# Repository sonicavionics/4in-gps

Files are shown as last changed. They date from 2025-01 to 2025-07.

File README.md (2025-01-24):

# GPS Module Repository

Use Export KiCad Images Workflow

---

<div align="center">
  <div>
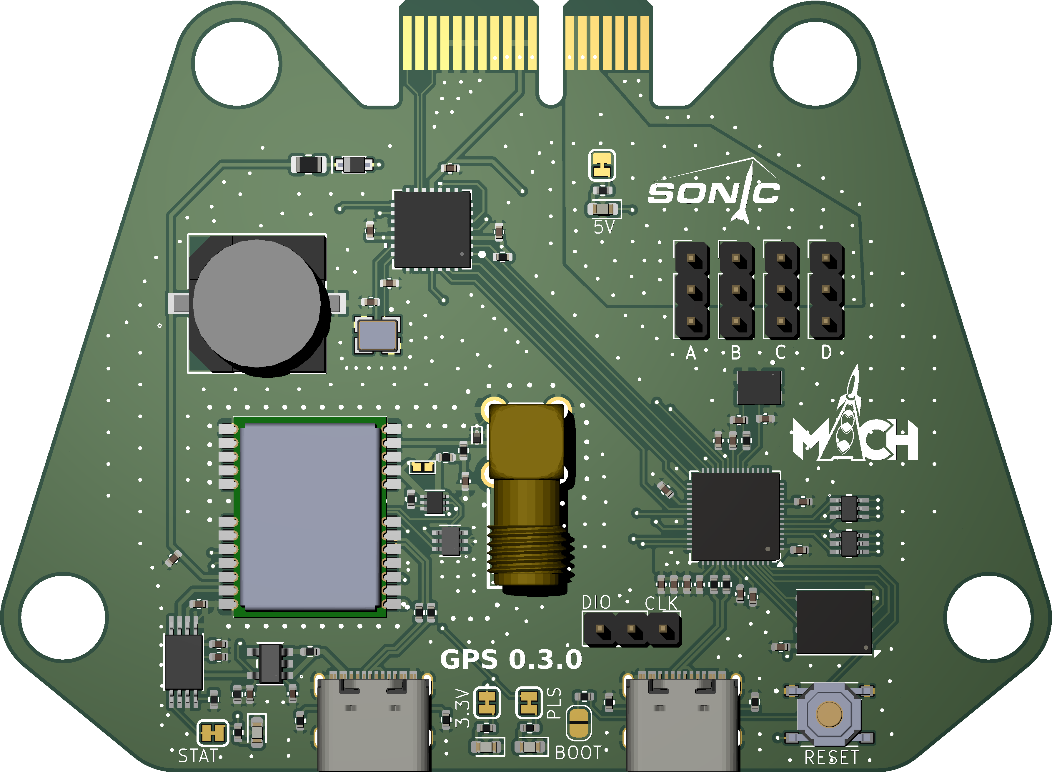
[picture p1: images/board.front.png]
    
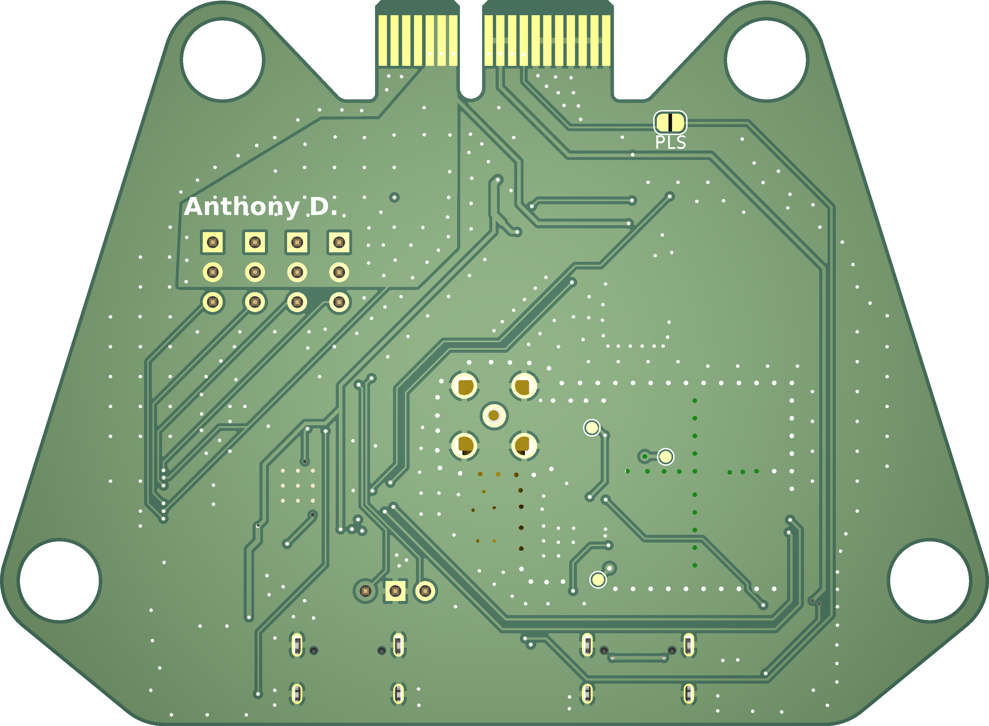
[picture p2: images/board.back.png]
    
    <p><em>3D Render</em></p>
  </div>
  <br>

  <div>
    Schematic<br>
    <p><em>Schematic</em></p>
  </div>
  <br>
  
  <div>
    Front
    Back<br>
    <em>Footprint</em>
  </div>
</div>

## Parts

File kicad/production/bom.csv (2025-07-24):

Designator | Footprint | Quantity | Value | LCSC Part #
BALLSACK1 | a5b3f77c-c1d0-4586-9ab7-7f2af37e3489 | 1
C1, C11, C13, C14, C15, C17, C18, C2, C20, C21, C22, C26, C27, C5, C6, C8, C9 | 0402 | 17 | 100n | C307331
C10, C12, C24, C25, C7 | 0402 | 5 | 1u | C52923
C16, C19 | 0402 | 2 | 22p | C1555
C3, C4 | 0402 | 2 | 15p | C1548
D1 | D_SOD-923 | 1 | PESD9R3.3ST5G | C2912536
D2 | SOD-323 | 1 | 0.5A/40V/420mV | C426868
D3 | 0603 | 1 | LED | C965808
D4, D6 | 0603 | 2 | LED | C2286
D5 | 0603 | 1 | LED | C2288
J2, J4 | USB_C_Receptacle_Palconn_UTC16-G | 2 | USB_C_Receptacle_USB2.0_16P | C2765186
L1 | 0402 | 1 | 27n >300mA | C12669
R1, R11, R12, R2 | 0402 | 4 | 5.1k | C25905
R10, R30 | 0402 | 2 | 100k | C25741
R13 | 0402 | 1 | 499R | C4125
R14, R20, R22, R8 | 0402 | 4 | 1k | C11702
R15, R6 | 0402 | 2 | 10k | C25744
R16, R17, R3, R4 | 0402 | 4 | 27 | C25100
R18 | 0402 | 1 | 2.4k | C25882
R5 | 0402 | 1 | 10R | C25077
R7 | 0402 | 1 | 270R | C25099
R9 | 0805 | 1 | 75R | C17820
RF1 | SMA-TH_BWSMA-KWE-Z001 | 1 | BWSMA-KWE-Z001 | C496551
S2 | SW_TS-1187A-B-A-B | 1 | TS-1187A-B-A-B | C318884
U1, U10 | DCK6 | 2 | SN74LVC2G17DCKR | C50714
U2 | WSON-8-1EP_6x5mm_P1.27mm_EP3.4x4.3mm | 1 | W25Q128JVP | C190862
U3 | QFN28_6X6MC_MCH | 1 | MCP25625T-E/ML | C191253
U4 | QFN-56-1EP_7x7mm_P0.4mm_EP3.2x3.2mm | 1 | RP2040 | C2040
U5 | XCVR_NEO-M9N-00B | 1 | NEO-M9N
U6 | SC-88&slash_SC70-6&slash_SOT-363_419B-02_ONS | 1 | NC7WZ07P6X | C95342
U7 | SOT-23-5_RIT_LDO | 1 | RT9013-33GB | C47773
U8 | PW8 | 1 | TPS2115APWR
U9 | SOT_X-T1-GE3_VIS | 1 | SI1016X-T1-GE3 | C142570
X1 | ABM8-272-T3_ABR | 1 | ABM8-272-T3 | C20625731
Y1 | OSC_X322516MLB4SI | 1 | X322516MLB4SI | C12668

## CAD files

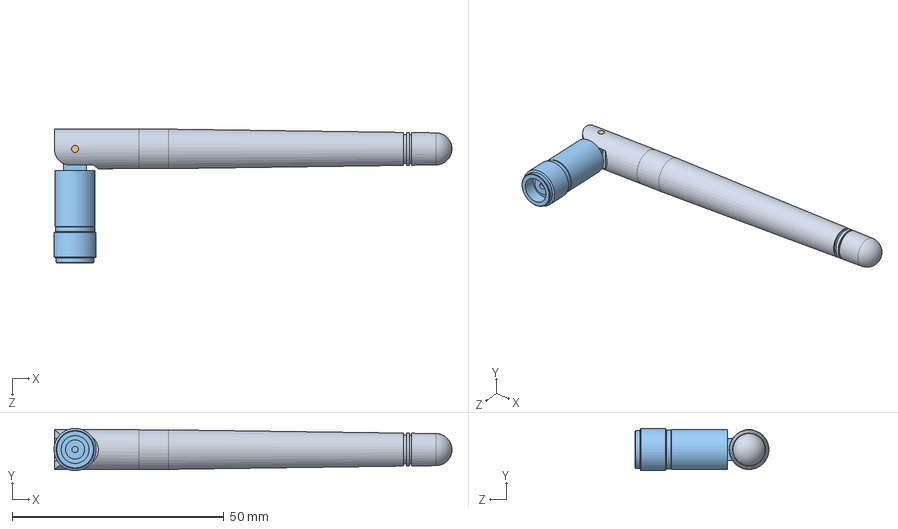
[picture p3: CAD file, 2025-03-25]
solidworks/Antenna.SLDASM
94.1 x 9.99 x 31.6 mm
bottom
joint
top

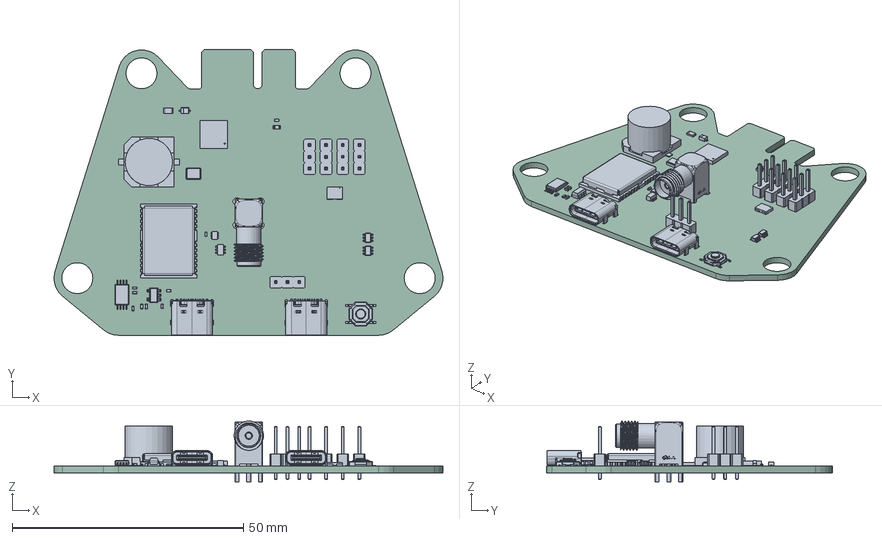
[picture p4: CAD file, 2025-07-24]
images/board.step
84.1 x 61.7 x 13.2 mm
R_0402_1005Metric x 5
LED_0603_1608Metric
R_0805_2012Metric
USB_C_Receptacle_GCT_USB4105-xx-A_16P_TopMnt_Horizontal x 2
PinHeader_1x03_P2.54mm_Vertical x 5
BODY-SOT x 2
LEAD-SOT x 12
PIN1-ID x 3
kicad_embedded_1868890EF3AC24624A4AA782DF9BD4FA
C_0402_1005Metric x 4
kicad_embedded_A65466E470E5E8AF14C115DF900A7CD7
kicad_embedded_2F32EEA5E615854C9557B2AC4C7BA695
kicad_embedded_4388890B492DB805848C6FA29B657E5E
kicad_embedded_F2E480E80373251B4C3F0A48D73F2CA5
kicad_embedded_1610E3370EAE01E3A2A39EE967F8174C
kicad_embedded_74EC9C574C356922F6A4535285956C6B
NEO-M9N_NEO-M9N
kicad_embedded_F4A6B9CFC55C68C8E2BC8E95A8C0B69D
kicad_embedded_83CB284321D7E3E886F8C67688601632
BODY-SO
LEAD-SO x 8
gps_PCB

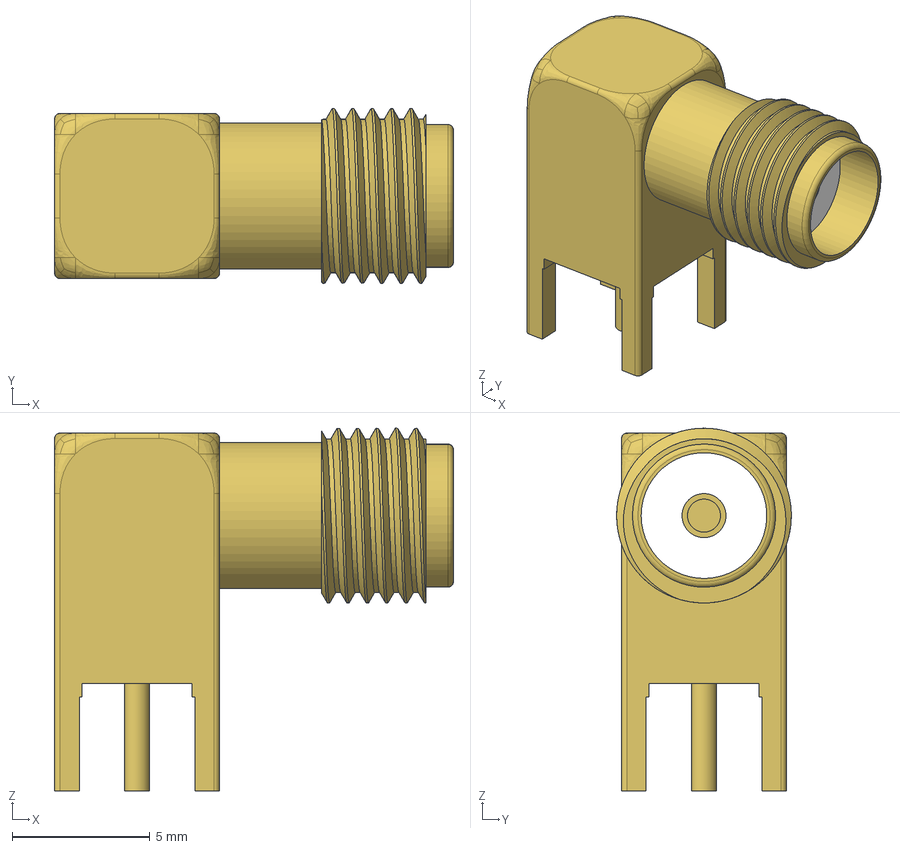
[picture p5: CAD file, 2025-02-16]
kicad/3d models/SMAthing.step
14.5 x 6.35 x 13.2 mm

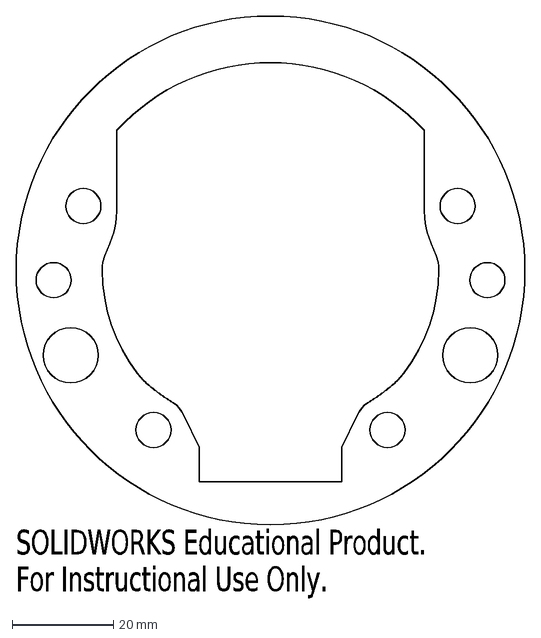
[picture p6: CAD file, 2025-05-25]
kicad/rack.DXF
SOLIDWORKS Educational Product.
For Instructional Use Only.

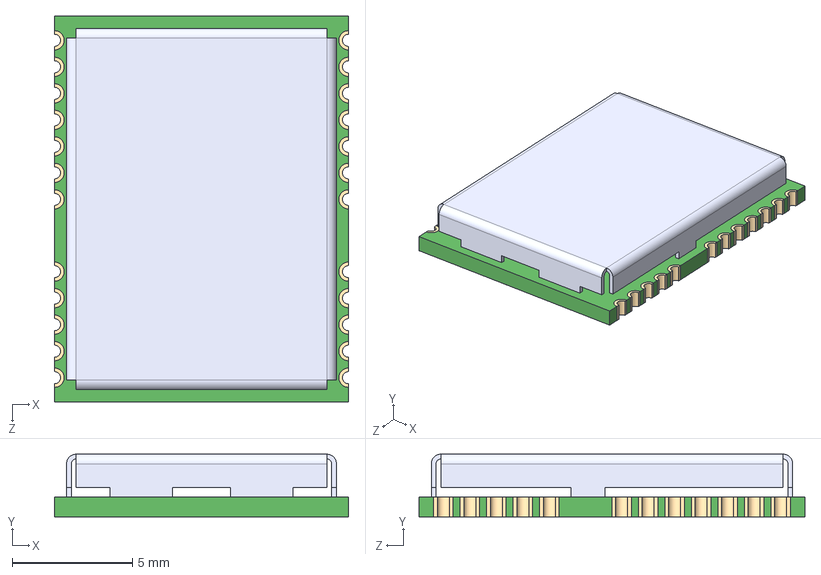
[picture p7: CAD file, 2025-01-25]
kicad/3d models/NEO-M9N-00B.step
12.2 x 2.60 x 16.0 mm

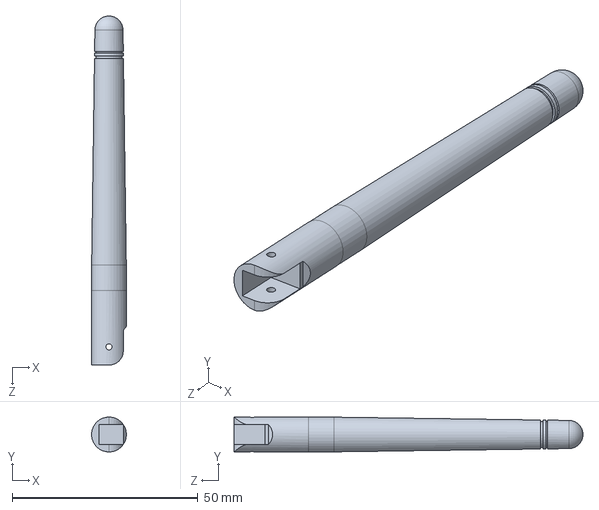
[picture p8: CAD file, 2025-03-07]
solidworks/top.SLDPRT
9.38 x 9.40 x 94.0 mm

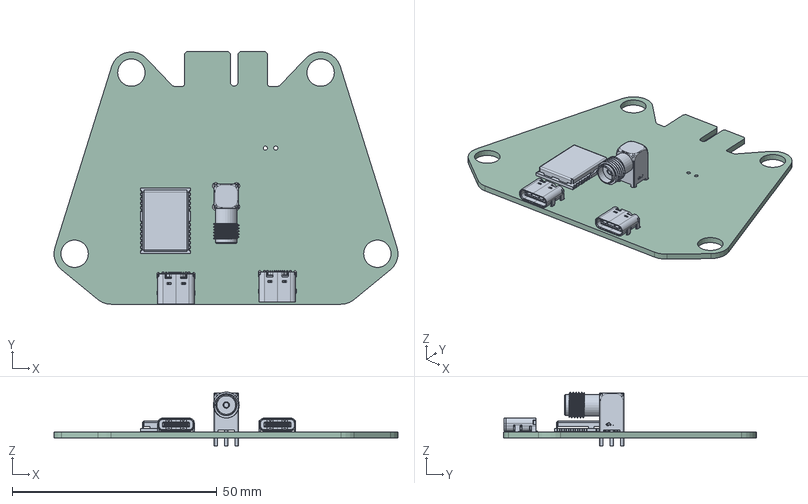
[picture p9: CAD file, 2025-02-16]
solidworks/gps.step
84.1 x 61.7 x 13.2 mm
USB_C_Receptacle_GCT_USB4105-xx-A_16P_TopMnt_Horizontal x 2
NEO-M9N_NEO-M9N
gps_PCB

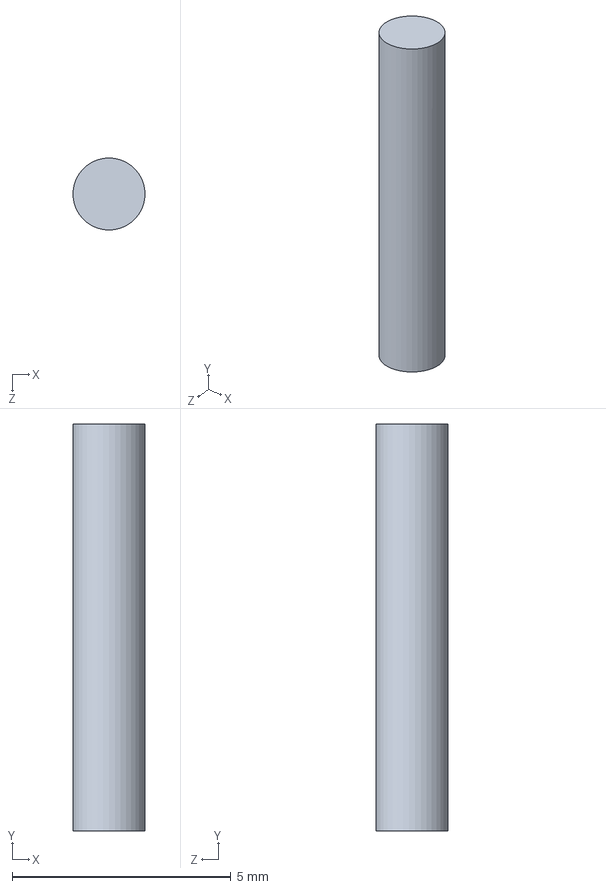
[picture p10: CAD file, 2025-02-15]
solidworks/joint.SLDPRT
1.64 x 9.31 x 1.65 mm

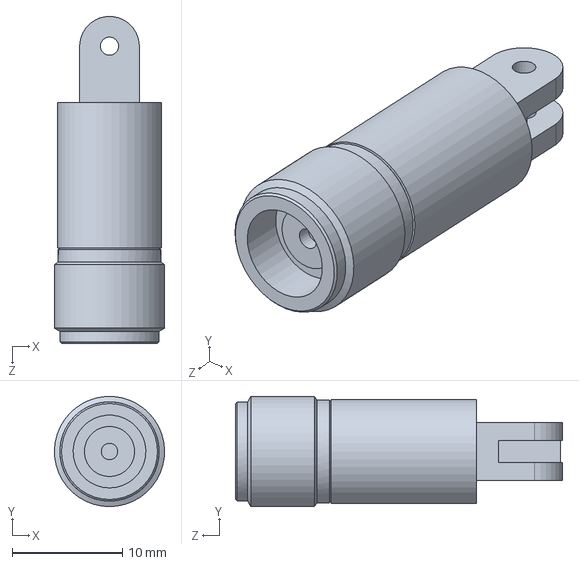
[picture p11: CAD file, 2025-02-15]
solidworks/bottom.SLDPRT
9.98 x 9.99 x 29.6 mm

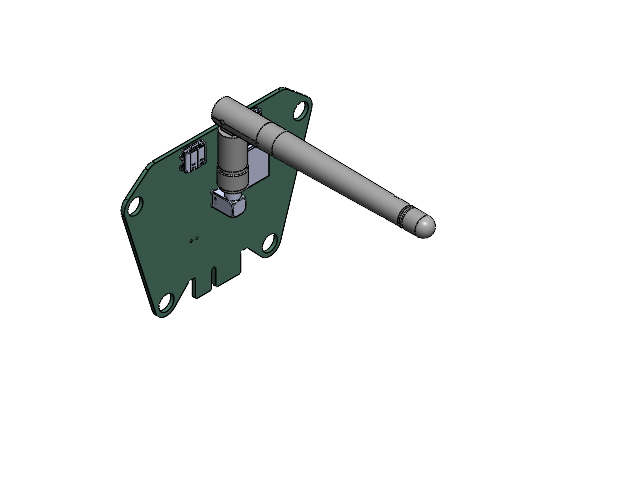
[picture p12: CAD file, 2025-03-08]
solidworks/gps_assembly.SLDASM
NEO-M9N_NEO-M9N_1.step
COMPOUND_1.step
SOLID_1.step
USB_C_Receptacle_GCT_USB4105-xx-A_16P_TopMnt_Horizontal_1.step x 2
gps_PCB_1.step
bottom
joint
top

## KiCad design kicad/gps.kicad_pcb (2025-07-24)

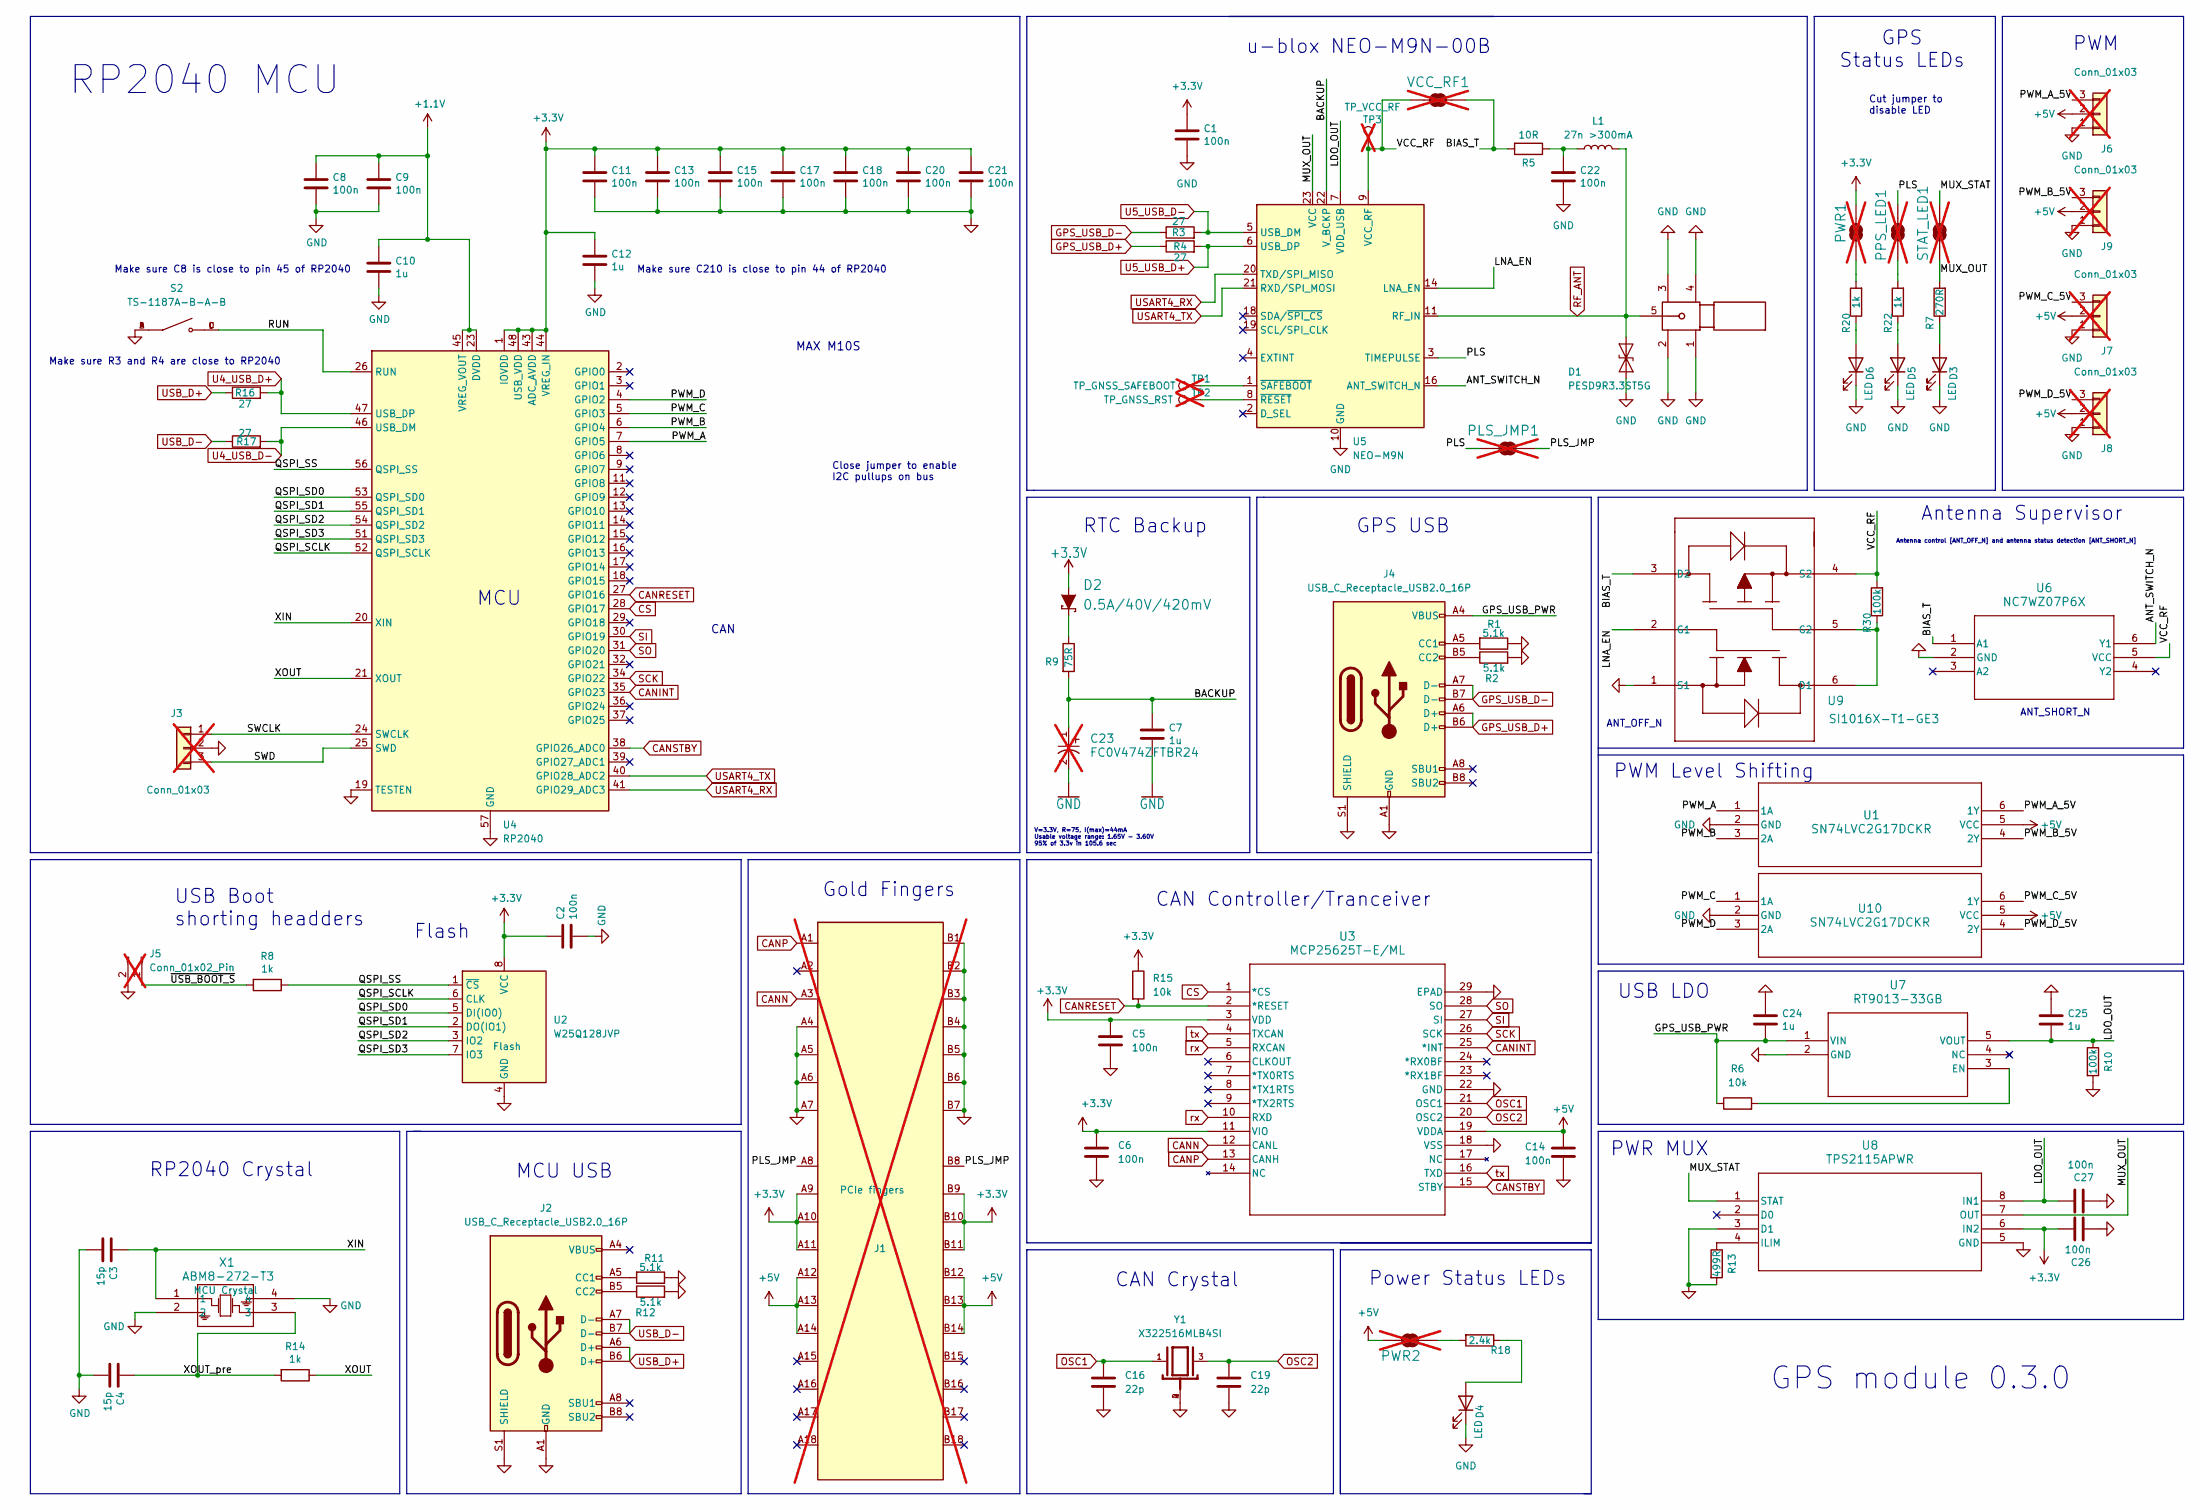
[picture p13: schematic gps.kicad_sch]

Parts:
C1, C2, C5, C6, C8, C9, C11, C13, C14, C15, C17, C18, C20, C21, C22, C26, C27: 100n; C_0402_1005Metric; LCSC Part # C307331
C3, C4: 15p; C_0402_1005Metric; LCSC Part # C1548
C7, C10, C12, C24, C25: 1u; C_0402_1005Metric; LCSC Part # C52923
C16, C19: 22p; C_0402_1005Metric; LCSC Part # C1555
C23: FC0V474ZFTBR24; FC0V474ZFTBR24_KEM; not fitted
D1: PESD9R3.3ST5G; D_SOD-923; LCSC C2912536
D2: 0.5A/40V/420mV; SOD-323; Manufacturer Part Number PMEGA4005EJ,115; LCSC Part # C426868
D3: LED; LED_0603_1608Metric; Manufacturer_Part_Number XL-1608UWC-04; LCSC Part # C965808
D4: LED; LED_0603_1608Metric; LCSC Part # C2286
D5: LED; LED_0603_1608Metric; Manufacturer_Part_Number KT-0603B; LCSC Part # C2288
D6: LED; LED_0603_1608Metric; Manufacturer_Part_Number KT-0603R; LCSC Part # C2286
J1: Bus_PCI_Express_x1; BUS_PCIexpress_x1; LCSC Part # n/a; not fitted
J2, J4: USB_C_Receptacle_USB2.0_16P; USB_C_Receptacle_Palconn_UTC16-G; LCSC Part # C2765186
J3: Conn_01x03; DEBUGHEADER; LCSC Part # n/a; not fitted
J5: Conn_01x02_Pin; SolderJumper-2_P1.3mm_Open_RoundedPad1.0x1.5mm; not fitted
J6, J7, J8, J9: Conn_01x03; PinHeader_1x03_P2.54mm_Vertical; LCSC Part # n/a; not fitted
L1: 27n >300mA; R_0402_1005Metric; Manufacturer Part Number LQG15HS27NJ02D; LCSC Part # C12669
PLS_JMP1: JUMPER-SMT_2_NC_TRACE_SILK; SolderJumper-2_P1.3mm_Open_RoundedPad1.0x1.5mm; not fitted
PPS_LED1: JUMPER-SMT_2_NC_TRACE_SILK; SMT-JUMPER_2_NC_TRACE_SILK; not fitted
PWR1, PWR2: JUMPER-SMT_2_NC_TRACE_SILK; SMT-JUMPER_2_NC_TRACE_SILK; not fitted
R1, R2, R11, R12: 5.1k; R_0402_1005Metric; LCSC Part # C25905
R3, R4, R16, R17: 27; R_0402_1005Metric; LCSC Part # C25100
R5: 10R; R_0402_1005Metric; Manufacturer Part Number 0402WGF100JTCE; LCSC Part # C25077
R6, R15: 10k; R_0402_1005Metric; LCSC Part # C25744
R7: 270R; R_0402_1005Metric; Manufacturer_Part_Number 0402WGF2700TCE; LCSC Part # C25099
R8, R14, R20, R22: 1k; R_0402_1005Metric; LCSC Part # C11702
R9: 75R; R_0805_2012Metric; Manufacturer_Part_Number 0805W8F750JT5E; LCSC Part # C17820
R10, R30: 100k; R_0402_1005Metric; Manufacturer Part Number 0402WGF1003TCE; LCSC Part # C25741
R13: 499R; R_0402_1005Metric; Manufacturer Part Number 0402WGF4990TCE; LCSC Part # C4125
R18: 2.4k; R_0402_1005Metric; Manufacturer_Part_Number 0402WGF2401TCE; LCSC Part # C25882
RF1: BWSMA-KWE-Z001; SMA-TH_BWSMA-KWE-Z001; Manufacturer Part Number BWSMA-KWE-Z001; LCSC Part # C496551
S2: TS-1187A-B-A-B; SW_TS-1187A-B-A-B; PARTREV A0; LCSC Part # C318884
STAT_LED1: JUMPER-SMT_2_NC_TRACE_SILK; SMT-JUMPER_2_NC_TRACE_SILK; not fitted
TP1: TP_GNSS_SAFEBOOT; TestPoint_Pad_D1.0mm; not fitted
TP2: TP_GNSS_RST; TestPoint_Pad_D1.0mm; not fitted
TP3: TP_VCC_RF; TestPoint_Pad_D1.0mm; not fitted
U1, U10: SN74LVC2G17DCKR; DCK6; MFR.Part # SN74LVC2G17DCKR; JLC Link JLCPCB Part
U2: W25Q128JVP; WSON-8-1EP_6x5mm_P1.27mm_EP3.4x4.3mm; LCSC C190862
U3: MCP25625T-E/ML; QFN28_6X6MC_MCH; LCSC Part # C191253
U4: RP2040; QFN-56-1EP_7x7mm_P0.4mm_EP3.2x3.2mm; LCSC C2040
U5: NEO-M9N; ublox_NEO
U6: NC7WZ07P6X; SC-88&slash_SC70-6&slash_SOT-363_419B-02_ONS; MFR.Part # NC7WZ07P6X; LCSC Part # C95342
U7: RT9013-33GB; SOT-23-5_RIT_LDO; MFR.Part # RT9013-33GB; LCSC Part # C47773
U8: TPS2115APWR; PW8
U9: SI1016X-T1-GE3; SOT_X-T1-GE3_VIS; Manufacturer Part Number SI1016X-T1-GE3; LCSC Part # C142570
VCC_RF1: JUMPER-SMT_2_NC_TRACE_SILK; SMT-JUMPER_2; not fitted
X1: ABM8-272-T3; ABM8-272-T3_ABR; LCSC Part # C20625731
Y1: X322516MLB4SI; OSC_X322516MLB4SI; PARTREV N/A; LCSC Part # C12668

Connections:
+1.1V: C8.1, C9.1, C10.1, U4.23 (DVDD), U4.45 (VREG_VOUT), U4.50 (DVDD)
+3.3V: C1.1, C2.1, C5.1, C6.1, C11.1, C12.1, C13.1, C15.1, C17.1, C18.1, C20.1, C21.1, C26.1, D2.A, J1.A9 (+3.3V), J1.A10 (+3.3V), J1.A11 (~PERST), J1.B9 (JTAG1), J1.B10 (3.3Vaux), J1.B11 (~WAKE), PWR1.2, R15.1, U2.8 (VCC), U3.3 (VDD), U3.11 (VIO), U4.1 (IOVDD), U4.10 (IOVDD), U4.22 (IOVDD), U4.33 (IOVDD), U4.42 (IOVDD), U4.43 (ADC_AVDD), U4.44 (VREG_IN), U4.48 (USB_VDD), U4.49 (IOVDD), U8.6 (IN2)
+5V: C14.1, J1.A12 (GND), J1.A13 (REFCLK+), J1.A14 (REFCLK-), J1.B12 (RSVD), J1.B13 (GND), J1.B14 (PETp0), J6.2, J7.2, J8.2, J9.2, PWR2.2, U1.5 (VCC), U3.19 (VDDA), U10.5 (VCC)
/ANT_SWITCH_N: U5.16 (ANT_SWITCH_N), U6.6 (Y1)
/BACKUP: C7.1, C23.1, R9.2, U5.22 (V_BCKP)
/BIAS_T: R5.2, U6.1 (A1), U9.3 (D2), VCC_RF1.1
/GPS_USB_PWR: C24.2, J4.A4 (VBUS), J4.A9 (VBUS), J4.B4 (VBUS), J4.B9 (VBUS), R6.1, U7.1 (VIN)
/LDO_OUT: C25.2, C27.1, R10.1, U5.7 (VDD_USB), U7.5 (VOUT), U8.8 (IN1)
/LNA_EN: U5.14 (LNA_EN), U9.2 (G1)
/MUX_OUT: R7.2, STAT_LED1.1, U5.23 (VCC), U8.7 (OUT)
/MUX_STAT: STAT_LED1.2, U8.1 (STAT)
/PLS: PLS_JMP1.2, PPS_LED1.2, U5.3 (TIMEPULSE); also elsewhere on the board
/PLS_JMP: J1.A8 (JTAG5), J1.B8 (+3.3V), PLS_JMP1.1; also elsewhere on the board
/PWM_A: U1.1 (1A), U4.7 (GPIO5)
/PWM_A_5V: J6.3, U1.6 (1Y)
/PWM_B: U1.3 (2A), U4.6 (GPIO4)
/PWM_B_5V: J9.3, U1.4 (2Y)
/PWM_C: U4.5 (GPIO3), U10.1 (1A)
/PWM_C_5V: J7.3, U10.6 (1Y)
/PWM_D: U4.4 (GPIO2), U10.3 (2A)
/PWM_D_5V: J8.3, U10.4 (2Y)
/QSPI_SCLK: U2.6 (CLK), U4.52 (QSPI_SCLK)
/QSPI_SD0: U2.5 (DI(IO0)), U4.53 (QSPI_SD0)
/QSPI_SD1: U2.2 (DO(IO1)), U4.55 (QSPI_SD1)
/QSPI_SD2: U2.3 (IO2), U4.54 (QSPI_SD2)
/QSPI_SD3: U2.7 (IO3), U4.51 (QSPI_SD3)
/QSPI_SS: R8.1, U2.1 (~CS), U4.56 (QSPI_SS)
/RUN: S2.C, S2.D, U4.26 (RUN)
/SWCLK: J3.1, U4.24 (SWCLK)
/SWD: J3.3, U4.25 (SWD)
/VCC_RF: R30.2, TP3.1, U5.9 (VCC_RF), U6.5 (VCC), U9.4 (S2), VCC_RF1.2
/XIN: C3.1, U4.20 (XIN), X1.1
/XOUT: R14.1, U4.21 (XOUT)
/XOUT_pre: C4.1, R14.2, X1.3
/~USB_BOOT_S: J5.1, R8.2
CANINT: U3.25 (*INT), U4.35 (GPIO23)
CANN: J1.A3 (+12V), U3.12 (CANL)
CANP: J1.A1 (~PRSNT1), U3.13 (CANH)
CANRESET: R15.2, U3.2 (*RESET), U4.27 (GPIO16)
CANSTBY: U3.15 (STBY), U4.38 (GPIO26_ADC0)
CS: U3.1 (*CS), U4.28 (GPIO17)
GND: C1.2, C2.2, C3.2, C4.2, C5.2, C6.2, C7.2, C8.2, C9.2, C10.2, C11.2, C12.2, C13.2, C14.2, C15.2, C16.2, C17.2, C18.2, C19.2, C20.2, C21.2, C22.2, C23.2, C24.1, C25.1, C26.2, C27.2, D1.1 (A1), D3.1 (K), D4.1 (K), D5.1 (K), D6.1 (K), J1.A4 (GND), J1.A5 (JTAG2), J1.A6 (JTAG3), J1.A7 (JTAG4), J1.B1 (+12V), J1.B2 (+12V), J1.B3 (+12V), J1.B4 (GND), J1.B5 (SMCLK), J1.B6 (SMDAT), J1.B7 (GND), J2.A1 (GND), J2.A12 (GND), J2.B1 (GND), J2.B12 (GND), J2.S1 (SHIELD), J3.2, J4.A1 (GND), J4.A12 (GND), J4.B1 (GND), J4.B12 (GND), J4.S1 (SHIELD), J5.2, J6.1, J7.1, J8.1, J9.1, R1.1, R2.2, R10.2, R11.1, R12.2, R13.2, RF1.1, RF1.2, RF1.3, RF1.4, S2.A, S2.B, U1.2 (GND), U2.4 (GND), U3.18 (VSS), U3.22 (GND), U3.29 (EPAD), U4.19 (TESTEN), U4.57 (GND), U5.10 (GND), U5.12 (GND), U5.13 (GND), U5.24 (GND), U6.2 (GND), U7.2 (GND), U8.3 (D1), U8.5 (GND), U9.1 (S1), U10.2 (GND), X1.2, X1.4, Y1.2, Y1.4
GPS_USB_D+: J4.A6 (D+), J4.B6 (D+), R4.1
GPS_USB_D-: J4.A7 (D-), J4.B7 (D-), R3.1
unnamed: C22.1, L1.1, R5.1
unnamed: D2.C, R9.1
unnamed: D3.2 (A), R7.1
unnamed: D4.2 (A), R18.1
unnamed: D5.2 (A), R22.1
unnamed: D6.2 (A), R20.1
unnamed: J2.A5 (CC1), R11.2
unnamed: J2.B5 (CC2), R12.1
unnamed: J4.A5 (CC1), R1.2
unnamed: J4.B5 (CC2), R2.1
unnamed: PPS_LED1.1, R22.2
unnamed: PWR1.1, R20.2
unnamed: PWR2.1, R18.2
unnamed: TP2.1, U5.8 (~RESET)
unnamed: TP1.1, U5.1 (~SAFEBOOT)
unnamed: R6.2, U7.3 (EN)
unnamed: R13.1, U8.4 (ILIM)
unnamed: R30.1, U9.5 (G2), U9.6 (D1)
OSC1: C16.1, U3.21 (OSC1), Y1.1
OSC2: C19.1, U3.20 (OSC2), Y1.3
RF_ANT: D1.2 (A2), L1.2, RF1.5, U5.11 (RF_IN)
SCK: U3.26 (SCK), U4.34 (GPIO22)
SI: U3.27 (SI), U4.30 (GPIO19)
SO: U3.28 (SO), U4.31 (GPIO20)
U4_USB_D+: R16.2, U4.47 (USB_DP)
U4_USB_D-: R17.2, U4.46 (USB_DM)
U5_USB_D+: R4.2, U5.6 (USB_DP)
U5_USB_D-: R3.2, U5.5 (USB_DM)
USART4_RX: U4.41 (GPIO29_ADC3), U5.20 (TXD/SPI_MISO)
USART4_TX: U4.40 (GPIO28_ADC2), U5.21 (RXD/SPI_MOSI)
USB_D+: J2.A6 (D+), J2.B6 (D+), R16.1
USB_D-: J2.A7 (D-), J2.B7 (D-), R17.1
rx: U3.5 (RXCAN), U3.10 (RXD)
tx: U3.4 (TXCAN), U3.16 (TXD)

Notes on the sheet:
Flash
CAN Crystal
GPS Status LEDs
CAN Controller/Tranceiver
Make sure R3 and R4 are close to RP2040
ANT_OFF_N
RP2040 MCU
Gold Fingers
GPS module 0.3.0
USB Boot shorting headders
u-blox NEO-M9N-00B
GPS USB
MCU
Antenna Supervisor
RTC Backup
PWM Level Shifting
Make sure C210 is close to pin 44 of RP2040
MAX M10S
MCU USB
Power Status LEDs
USB LDO
Cut jumper to disable LED
PWR MUX
ANT_SHORT_N
V=3.3V, R=75, I(max)=44mA Usable voltage range: 1.65V - 3.60V 95% of 3.3v in 105.6 sec
RP2040 Crystal
Antenna control [ANT_OFF_N] and antenna status detection [ANT_SHORT_N]
CAN
Make sure C8 is close to pin 45 of RP2040
Close jumper to enable I2C pullups on bus
PWM

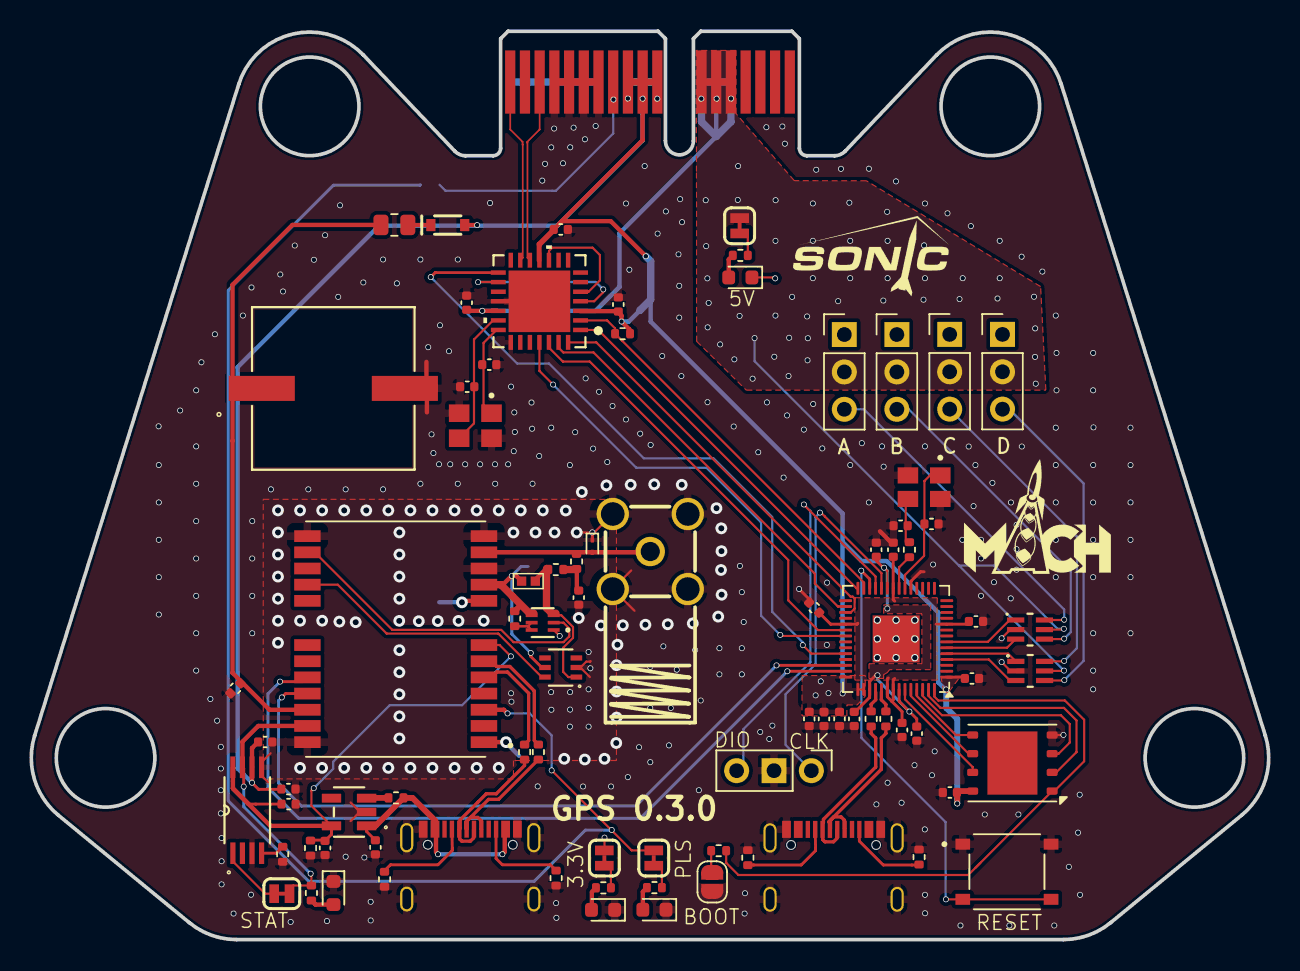
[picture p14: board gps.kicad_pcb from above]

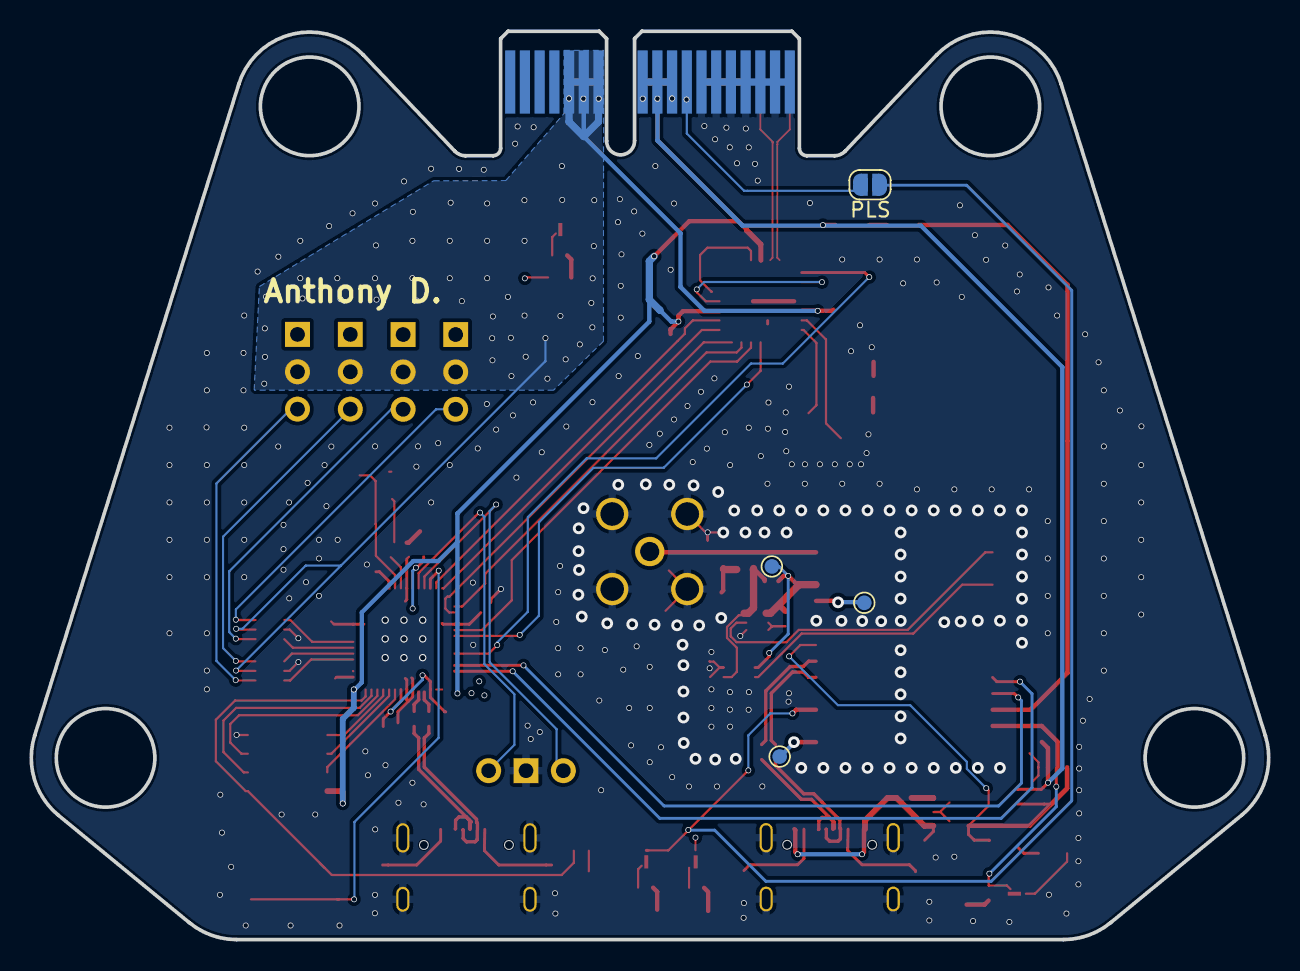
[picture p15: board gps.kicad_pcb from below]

Board: 4 copper layers, 84.1 x 61.7 mm, 88 parts (5 on the bottom side), 78 nets.

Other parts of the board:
PLS: JUMPER-SMT_2_NC_TRACE_SILK; SolderJumper-2_P1.3mm_Open_RoundedPad1.0x1.5mm
ballsack1: a5b3f77c-c1d0-4586-9ab7-7f2af37e3489

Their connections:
/PLS: PLS.2; also elsewhere on the board
/PLS_JMP: PLS.1; also elsewhere on the board

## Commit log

2025-01-24 Initial commit: M10S PCB design
    Created the initial PCB design for the M10S module. Used template files from the 4in-sensors KiCad repository as a starting point for the layout and design. Adjusted components and schematics to fit 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
    [gps.kicad_pcb, gps.kicad_sch]
2025-01-24 Renamed gps folder to kicad
    [gps.kicad_pcb, gps.kicad_sch]
2025-01-24 Auto-exported schematic, PCB, and 3D model
    [board.step]
2025-01-24 Update footprint to match sensor 0.2.0
    [gps.kicad_pcb]
2025-01-24 Update schematic: added power and function LEDs for GPS
    [gps.kicad_sch]
2025-01-25 Switch from MAX M10S to NEO-M9N for enhanced GPS performance
    Switched from MAX M10S to NEO-M9N for improved GPS preformance. The NEO-M9N offers faster position acquisition with concurrent GNSS support (GPS, Galileo, GLONASS, BeiDou), higher accuracy, and up to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
    [NEO-M9N-00B.step, gps.kicad_pcb, gps.kicad_sch]
2025-01-26 Delete kicad/New CATIA Drawing.CATDrawing
    Deleted an unintended file that was mistakenly added to the repository.
2025-01-26 Update images
    [board.step]
2025-02-03 Add USB hub
    [gps.kicad_sch]
2025-02-03 update pcb
    [gps.kicad_pcb, gps.kicad_sch, gpsold.kicad_pcb]
2025-02-03 Remove outdated file gpsold
    [gps.kicad_pcb, gpsold.kicad_pcb]
2025-02-15 Update footprints
    [gps.kicad_sch]
2025-02-15 Add CAD for antenna
    [Antenna.SLDASM, bottom.SLDPRT, joint.SLDPRT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]
2025-02-15 Update antenna position
    [SMAthing.step, gps.kicad_pcb]
2025-03-07 Update antenna
    [Antenna.SLDASM, top.SLDPRT]
2025-03-07 add board.step to solidworks folder
    [board.step]
2025-03-07 create inital gps board assembly
    [gps_assembly.SLDASM]
2025-03-07 make antenna 90 degrees
    [Antenna.SLDASM]
2025-03-07 increase to 7 modules
    [gps_assembly.SLDASM]
2025-03-07 rotate antenna
    [gps_assembly.SLDASM]
2025-03-09 update assemblies
    [Antenna.SLDASM]
2025-03-25 update Antenna.SLDASM file
    [Antenna.SLDASM]
2025-05-04 Add MOSFET bias-tee switch for active GPS antenna
    [gps.kicad_sch]
2025-05-04 Finish GPS routing and LNA control
    - Added LNA_EN switch circuit with IRLML6344
    - Finalized VCC_RF routing and return path
    - Cleaned up UART1 connection on GPIO28/29
    [gps.kicad_pcb, gps.kicad_sch]
2025-05-04 Update all component properites
    [gps.kicad_pcb, gps.kicad_sch]
2025-05-04 Organize Schematic
    [gps.kicad_sch]
2025-05-06 remove *.kicad_prl and add to gitignore
2025-05-19 Fix MCU Ground Pour
    [gps.kicad_pcb]
2025-05-19 Fix DRC Violations
    [gps.kicad_pcb, gps.kicad_sch]
2025-05-19 Via Stitch
    [bom.csv, designators.csv, gps.PcbDoc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]
2025-05-25 Add TVS Diode
    [gps.kicad_sch]
2025-05-25 Add TVS Diode to footprint
    [gps.kicad_pcb, gps.kicad_sch]
2025-05-25 Update gate resistor value and apply general BOM improvements
    - Changed gate resistor R6 from 10kΩ to 2.2kΩ to improve MOSFET switching speed while maintaining safe drive current for LNA_EN pin.
    - Updated associated resistor part to a 0402 UNI-ROYAL 2.2kΩ variant with high stock from JLCPCB.
    - Refined BOM fields for several components including RF connector (RF1) and battery holder (BAT1) to match R5 formatting.
    - Ensured consistent metadata across all key parts: datasheets, LCSC part numbers, and manufacturer info.
    [gps.kicad_pcb, gps.kicad_sch]
2025-05-25 Update LED Positions
    Move LEDs to the front of the board for 3.3V and 5V power
    [gps.kicad_pcb, gps.kicad_sch]
2025-05-25 Move Gps Silkscreen to Front of Board
    [gps.kicad_pcb, gps.kicad_sch]
2025-05-25 update rack outline dxf
    [gps.kicad_pcb, rack.DXF]
2025-05-25 Update Files to KiCad 9.0
    [gps.kicad_pcb, gps.kicad_sch]
2025-05-25 Fix Battery Position
    [gps.kicad_pcb, gps.kicad_sch]
2025-06-07 Update components for order
    [gps.kicad_pcb, gps.kicad_sch]
2025-06-07 Move Boot pins
    [gps.kicad_pcb]
2025-06-07 Fix Usb Position
    [bom.csv, designators.csv, gps.kicad_pcb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]
2025-06-07 Generate Fabrication Files
    [bom.csv, designators.csv, gps.kicad_pcb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]
2025-06-07 Final Commit before 0.2.0 Order
    [bom.csv, gps.kicad_pcb, gps.kicad_sch]
2025-06-21 Add USB detection
    [gps.kicad_pcb, gps.kicad_sch]
2025-07-23 Big Fixes
    [gps.kicad_sch]
2025-07-23 Add Supercap
    [gps.kicad_sch]
2025-07-23 Major updates
    [gps.kicad_pcb, gps.kicad_sch]
2025-07-23 UPDATES
    - Updated antenna short-circuit monitor in accordance with MAX-M10S documentation
    - Added LDO from USB power to address issue where NEO-M9N did not recognize USB connection
    - Implemented power multiplexer prioritizing USB LDO; board can now be powered via USB, battery, or PowerSim
    - If USB is not connected, power negotiation defaults to the 3.3V board rail
    - Added VCC_RF bypass option allowing direct connection to Bias-T
    *Add test points
    *Complete footprinting for new components
    [gps.kicad_sch]
2025-07-23 Major Fixes
    Fixed impedances in accordance to JLC04161H-7628 Stackup
    Implemented footprinting for all components mentioned in last commit
    minor schematic tweaks and additions
    [gps.kicad_pcb, gps.kicad_sch]
2025-07-23 Add Bypasses
    [gps.kicad_pcb, gps.kicad_sch]
2025-07-24 Add Servo Outputs
    [gps.kicad_pcb, gps.kicad_sch]
2025-07-24 Fixed Stackup
    [gps.kicad_pcb, gps.kicad_sch]
2025-07-24 Add Power Zone for Servos
    [gps.kicad_pcb]
2025-07-24 Production File Generation
    [bom.csv, designators.csv, gps.kicad_pcb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]
